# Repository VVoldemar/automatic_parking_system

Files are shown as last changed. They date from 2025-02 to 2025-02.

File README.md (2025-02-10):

# Automatic Parking System

<div>
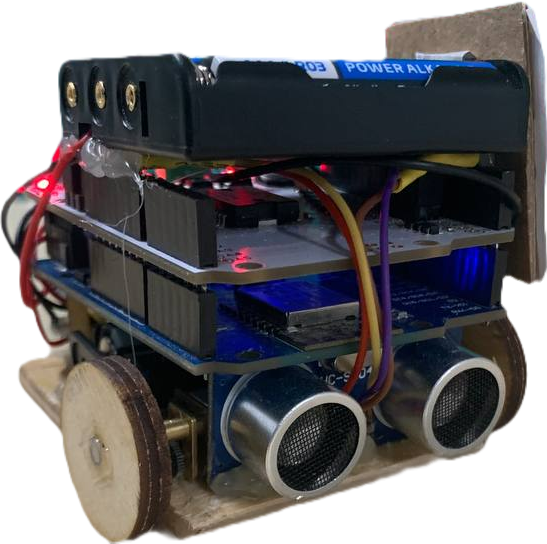
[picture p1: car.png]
    
    Данный репозиторий содержит материалы проекта "Модель автоматической парковки", разработанного для участия в Московской предпрофессиональной олимпиаде школьников, профиль "Инженерия".
</div>

## Описание проекта

Проект представляет собой программно-аппаратный комплекс (ПАК), реализующий автоматическую парковку модели автомобиля.  Система включает в себя следующие подсистемы:

*   **ПРА (Подсистема распознавания автомобиля):**  Отвечает за идентификацию автомобиля по QR-коду.
*   **ППЯ (Подсистема перемещения ячеек):**  Обеспечивает перемещение ячеек парковки.
*   **ПАУ (Подсистема автоматического управления):**  Координирует работу всех подсистем, управляет процессом парковки и хранения данных.
*   **ПБА (Подсистема беспилотного автомобиля):**  Модель автомобиля, способная к автономному перемещению.

## Внешний вид пользовательского интерфейса
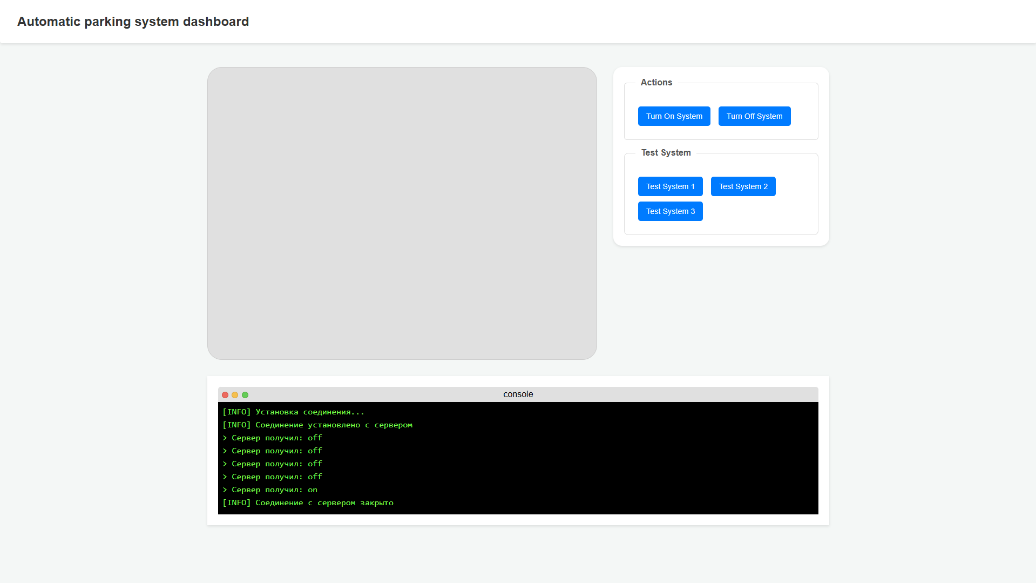
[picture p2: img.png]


_Предоставлен исключительно для справки, может отличаться_

## Структура репозитория

*   **Программный код:** Исходный код программного обеспечения ПАК.
*   **3D-модели:** Файлы 3D-моделей элементов системы.
*   **Видеоролик:** Ссылка на видеоролик, демонстрирующие работу системы.
*   **Фото:** Фотографии устройства

## Сборка и запуск
1.  Установите необходимые библиотеки: `pip install -r requirements.txt`
2.  Подключите Arduino к компьютеру.
3.  Загрузите скетч `esp.ino` на модуль на основе ESP8266.
4.  Запустите программу: `python main.py`

- Для просмотра модели общей сборки проекта, используйте программу **SolidWorks**

## Команда

*   Еремкин Степан
*   Вершок Владимир
*   Шишкин Степан
*   Брюханов Михаил
*   Пикулин Виктор
*   Руководитель: Шапошников Филипп Владимирович

_Подробное описание проекта, технические характеристики, результаты испытаний и прочая информация содержатся в отчетной документации._

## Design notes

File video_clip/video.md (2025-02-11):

Ссылка на видеоролик: https://vkvideo.ru/video506153733_456239018?list=ln-Q410VyUmrbDWpCRAAN

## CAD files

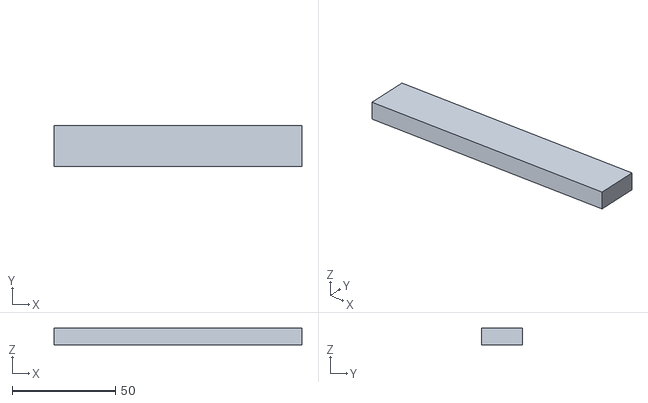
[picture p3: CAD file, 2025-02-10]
3d_models/предпроф ножка всего.STL
120.0 x 20.0 x 8.00

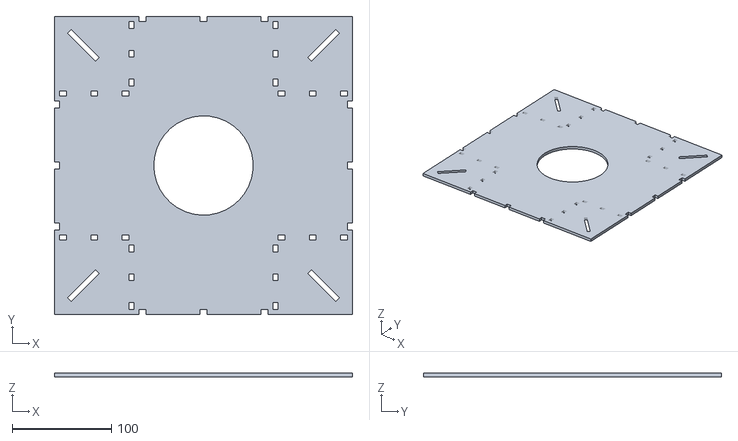
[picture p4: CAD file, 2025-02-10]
3d_models/предпроф 2 этаж.STL
300.0 x 300.0 x 4.00

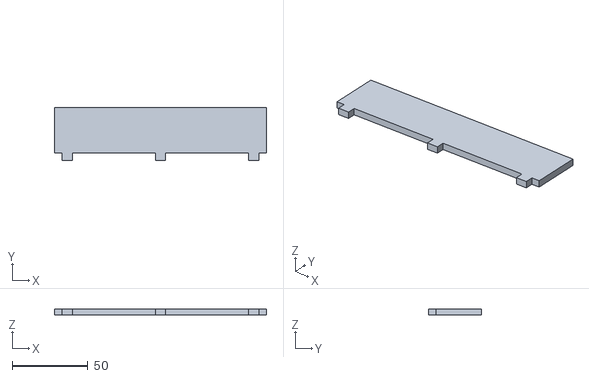
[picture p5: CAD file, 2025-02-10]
3d_models/предпроф бортик большой.STL
140.0 x 35.0 x 4.00

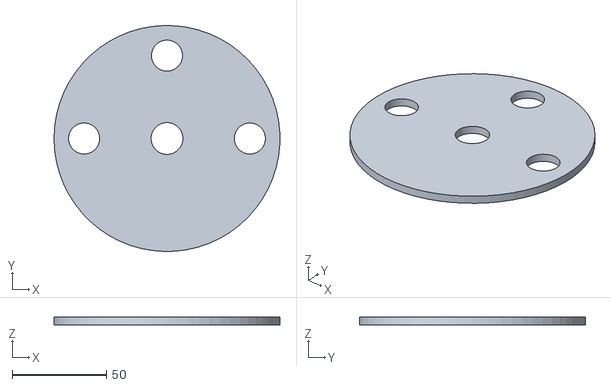
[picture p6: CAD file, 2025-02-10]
3d_models/предпроф колесо лифта верхнее 120мм.STL
120.0 x 120.0 x 4.00

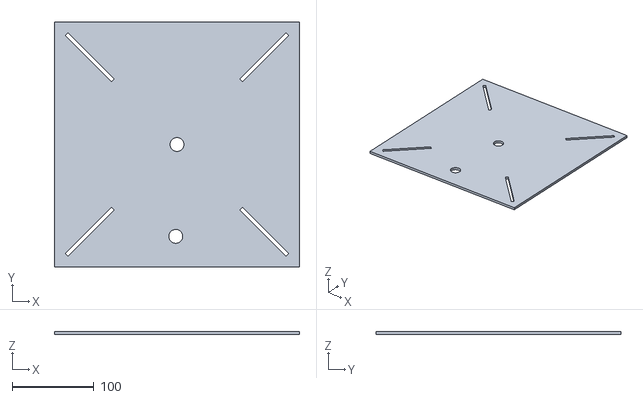
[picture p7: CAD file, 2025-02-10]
3d_models/предпроф основание подвала.STL
300.0 x 300.0 x 4.00

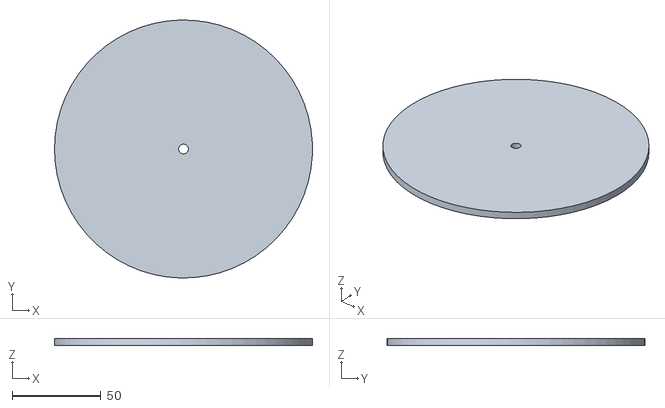
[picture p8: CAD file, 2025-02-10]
3d_models/предпроф колесо лифта нижнее 145мм.STL
145.0 x 145.0 x 4.00

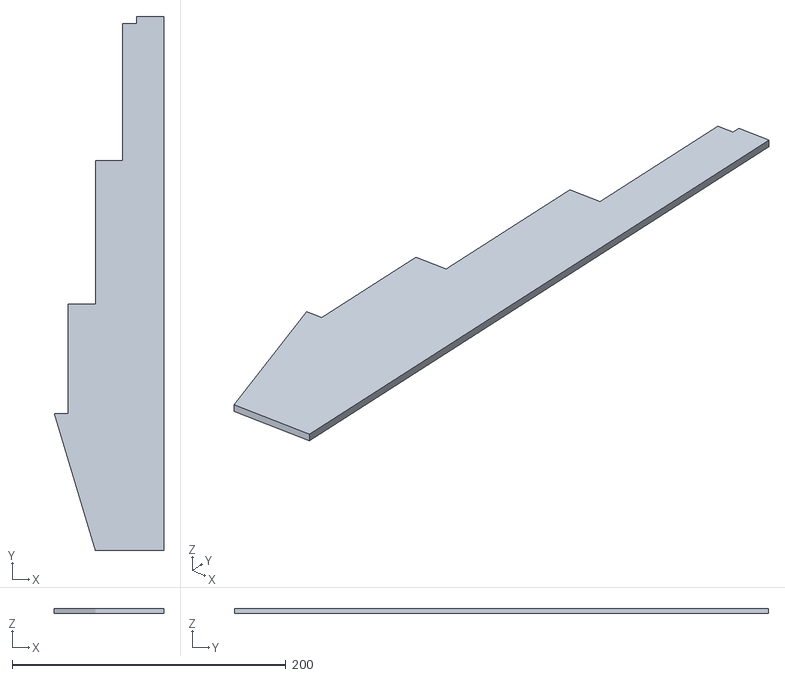
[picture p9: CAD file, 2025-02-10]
3d_models/предпроф опора чтоб ты в аду горела.STL
80.0 x 390.0 x 4.00

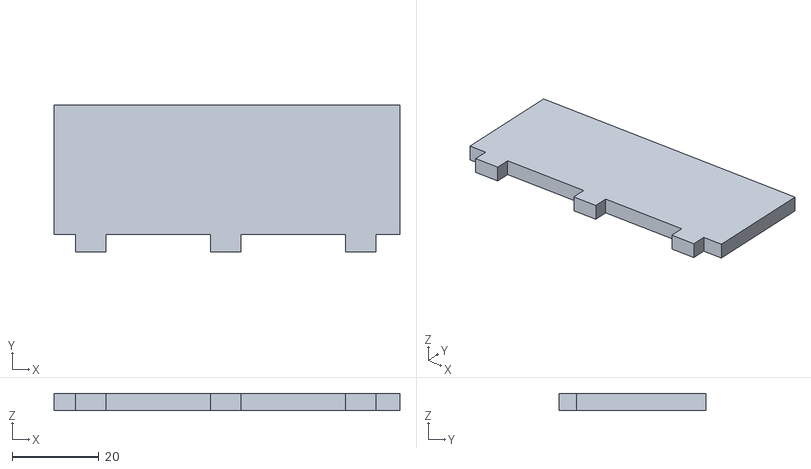
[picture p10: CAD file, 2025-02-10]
3d_models/предпроф бортик малый 1.STL
80.0 x 34.1 x 4.00

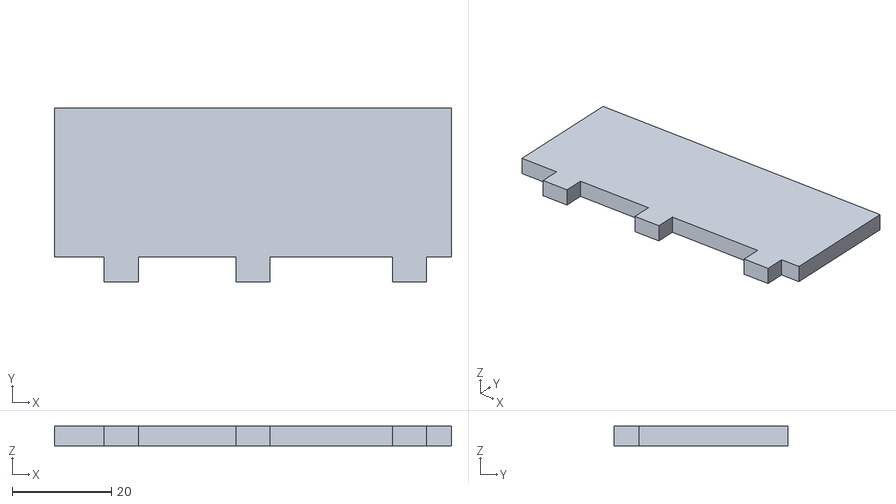
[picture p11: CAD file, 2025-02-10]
3d_models/предпроф бортик малый 10мм.STL
80.0 x 35.0 x 4.00

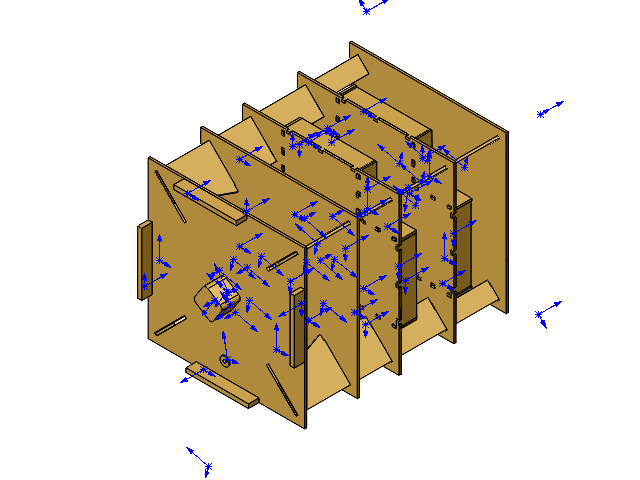
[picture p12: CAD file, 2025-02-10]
3d_models/предпроф сборка надеюсь конечная.SLDASM
предпроф основание подвала
предпроф ножка всего x 4
предпроф опора чтоб ты в аду горела x 4
предпроф заезд
предпроф 1 этаж
предпроф бортик большой x 8
предпроф бортик малый по 5мм x 7
предпроф бортик малый 10мм x 9
предпроф 2 этаж
предпроф потолок
предпроф подшибник x 7
предпроф колесо лифта нижнее 145мм
предпроф размер шагового двигателя x 4
предпроф шпилька двигателя x 4
предпроф шпилька лифта x 3
предпроф платформа лифта 95мм
предпроф колесо лифта верхнее 120мм
предпроф шпилька 6мм 40мм

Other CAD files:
3d_models/предпроф заезд.STL
3d_models/предпроф 1 этаж.STL

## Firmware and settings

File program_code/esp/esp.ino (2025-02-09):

#include <ESP8266WiFi.h>
// #include <MQTTClient.h>
#include <MQTT.h>

#define LEFT_WHEEL D5
#define RIGHT_WHEEL D6
#define LEFT_WHEEL_DIRECTION D4 
#define RIGHT_WHEEL_DIRECTION D7

#define TRIG_PIN D2
#define ECHO_PIN D3

#define SOUND_SPEED 0.034

// #define NO_DISTANCE_MODULE

const char WIFI_SSID[] = "MQTTT-1";
const char WIFI_PASSWORD[] = "11223344";

const char MQTT_BROKER_ADRRESS[] = "10.42.0.1";
const int MQTT_PORT = 1883;
const char MQTT_CLIENT_ID[] = "esp";
const char MQTT_USERNAME[] = "";
const char MQTT_PASSWORD[] = "";

const char PUBLISH_TOPIC[] = "esp";
const char SUBSCRIBE_TOPIC[] = "rasp";

const int PUBLISH_INTERVAL = 10000;

WiFiClient network;
MQTTClient mqtt = MQTTClient(256);

unsigned long lastPublishTime = 0;

int forward_stop_distance = 5;
int backward_stop_distance = 5;
int left_motor_speed = 255;
int right_motor_speed = 255;
int delay_after_distance = 200;

void setup() {
  Serial.begin(9600);

  pinMode(D4, OUTPUT);
  pinMode(D5, OUTPUT);
  pinMode(D6, OUTPUT);
  pinMode(D7, OUTPUT);
  pinMode(TRIG_PIN, OUTPUT);
  pinMode(ECHO_PIN, INPUT);

  int status = WL_IDLE_STATUS;
  while (status != WL_CONNECTED) {
    Serial.print("Arduino - Attempting to connect to SSID: ");
    Serial.println(WIFI_SSID);
    status = WiFi.begin(WIFI_SSID, WIFI_PASSWORD);
    Serial.println(status);
    delay(5000);
  }

  Serial.print("IP Address: ");
  Serial.println(WiFi.localIP());

  connectToRB();

  sendToRB("hello");
}

void loop() {
  mqtt.loop();

  if (millis() - lastPublishTime > PUBLISH_INTERVAL) {
    sendToRB(String(millis()));
    lastPublishTime = millis();
  }
}

void connectToRB() {
  mqtt.begin(MQTT_BROKER_ADRRESS, MQTT_PORT, network);

  mqtt.onMessage(messageHandler);

  Serial.print("Arduino - Connecting to MQTT broker");

  while (!mqtt.connect(MQTT_CLIENT_ID, MQTT_USERNAME, MQTT_PASSWORD)) {
    Serial.print(".");
    delay(100);
  }
  Serial.println();

  if (!mqtt.connected()) {
    Serial.println("Arduino - MQTT broker Timeout!");
    return;
  }

  if (mqtt.subscribe(SUBSCRIBE_TOPIC)){
    Serial.print("Arduino - Subscribed to the topic: ");
  } else {
    Serial.print("Arduino - Failed to subscribe to the topic: ");
  }

  Serial.println(SUBSCRIBE_TOPIC);
  Serial.println("Arduino - MQTT broker Connected!");
}

void sendToRB(const String &data) {
  mqtt.publish(PUBLISH_TOPIC, data);

  Serial.print("Arduino - sent to MQTT:");
  Serial.println(data);
}

void setConfig(String &payload) {
  // parse the payload and set the config
  switch (payload[6])
  { 
  case 'F':
    forward_stop_distance = payload.substring(8).toFloat();
    break;
  case 'B':
    backward_stop_distance = payload.substring(8).toFloat();
    break;
  case 'L':
    left_motor_speed = payload.substring(8).toFloat();
    break;
  case 'R':
    right_motor_speed = payload.substring(8).toFloat();
    break;
  case 'D':
    delay_after_distance = payload.substring(8).toInt();
    break;
  }
  Serial.println("Arduino - set config: " + 
    String(forward_stop_distance) + " " + 
    String(backward_stop_distance) + " " +
    String(left_motor_speed) + " " +
    String(right_motor_speed) + " " +
    String(delay_after_distance));

  sendToRB("ok config");
}

void messageHandler(String &topic, String &payload) {
  if (payload.length() >= 6 && payload.substring(0, 6) == "config"){
    setConfig(payload);
  }

  else if (payload == "forward"){
    moveForward();
  }

  else if (payload == "backward"){
    moveBackward();
  }
}

void moveForward(){
  sendToRB("ok forward");  // why just don't use json?

  analogWrite(LEFT_WHEEL, left_motor_speed);
  analogWrite(RIGHT_WHEEL, right_motor_speed);
  digitalWrite(LEFT_WHEEL_DIRECTION, LOW);
  digitalWrite(RIGHT_WHEEL_DIRECTION, HIGH);

  while (!enoughDistance(forward_stop_distance)){
    delay(100);
  }

  delay(delay_after_distance);

  digitalWrite(LEFT_WHEEL, LOW);
  digitalWrite(RIGHT_WHEEL, LOW);
  digitalWrite(LEFT_WHEEL_DIRECTION, LOW);
  digitalWrite(RIGHT_WHEEL_DIRECTION, LOW);

  sendToRB("done forward");  // why just don't use json?
}

bool enoughDistance(int &dist){
#ifdef NO_DISTANCE_MODULE
  delay(2000);
  return true;
#else
  return getDistance() <= dist;
#endif
}

float getDistance(){
  digitalWrite(TRIG_PIN, LOW);
  delayMicroseconds(2);

  digitalWrite(TRIG_PIN, HIGH);
  delayMicroseconds(10);
  digitalWrite(TRIG_PIN, LOW);
  
  long duration = pulseIn(ECHO_PIN, HIGH);
  float distanceCm = duration * SOUND_SPEED / 2.0;

  Serial.print("Distance (cm): ");
  Serial.println(distanceCm);
  return distanceCm;
}

void moveBackward(){
  sendToRB("ok backward");  // why just don't use json?

  analogWrite(LEFT_WHEEL, left_motor_speed);
  analogWrite(RIGHT_WHEEL, right_motor_speed);
  digitalWrite(LEFT_WHEEL_DIRECTION, HIGH);
  digitalWrite(RIGHT_WHEEL_DIRECTION, LOW);

  delay(delay_after_distance);

  while (enoughDistance(backward_stop_distance)){
    delay(100);
  }

  digitalWrite(LEFT_WHEEL, LOW);
  digitalWrite(RIGHT_WHEEL, LOW);
  digitalWrite(LEFT_WHEEL_DIRECTION, LOW);
  digitalWrite(RIGHT_WHEEL_DIRECTION, LOW);

  sendToRB("done backward");  // why just don't use json?
}

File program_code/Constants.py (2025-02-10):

STEPS_IN_360DEG = -1620
STEPS_IN_QUATER_ROTATION = STEPS_IN_360DEG // 4

STEPS_IN_FLOOR1 = -12500
STEPS_IN_FLOOR2 = -16900
STEPS_IN_BOTH_FLOORS = STEPS_IN_FLOOR1 + STEPS_IN_FLOOR2

DELAY_VERTICAL = 500 * 1e-6
DELAY_HORIZONTAL = 2000 * 1e-6  

MOTOR_VERTICAL1_PULSE = 5
MOTOR_VERTICAL1_DIRECTION = 6
MOTOR_VERTICAL2_PULSE = 23
MOTOR_VERTICAL2_DIRECTION = 24
MOTOR_VERTICAL3_PULSE = 20
MOTOR_VERTICAL3_DIRECTION = 21

MOTOR_HORIZONTAL_PULSE = 17
MOTOR_HORIZONTAL_DIRECTION = 27

FORWARD_STOP_DISTANCE = 4
BACKWARD_STOP_DISTANCE = 10

LEFT_MOTOR_SPEED = 60
RIGHT_MOTOR_SPEED = 55

AFTER_STOP_DISTANCE_DELAY = 600

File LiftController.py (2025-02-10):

from MotorController import MotorController
import Constants
from typing import Union
import logging

class LiftController:
    vertical_motors: list[MotorController]
    horizontal_motor: MotorController

    rotation: int # clockwise increases
    floor: int

    def __init__(self,
                 horizontal_motor: Union[MotorController, None] = None,
                 vertical_motors: Union[list[MotorController], None] = None):
        if not horizontal_motor:
            horizontal_motor = MotorController(
                Constants.MOTOR_HORIZONTAL_DIRECTION,
                Constants.MOTOR_HORIZONTAL_PULSE,
                Constants.DELAY_HORIZONTAL
            )
        if not vertical_motors:
            vertical_motors = [
                MotorController(
                    Constants.MOTOR_VERTICAL1_DIRECTION,
                    Constants.MOTOR_VERTICAL1_PULSE,
                    Constants.DELAY_VERTICAL
                ),
                MotorController(
                    Constants.MOTOR_VERTICAL2_DIRECTION,
                    Constants.MOTOR_VERTICAL2_PULSE,
                    Constants.DELAY_VERTICAL
                ),
                MotorController(
                    Constants.MOTOR_VERTICAL3_DIRECTION,
                    Constants.MOTOR_VERTICAL3_PULSE,
                    Constants.DELAY_VERTICAL
                ),
            ]
            
        self.vertical_motors = vertical_motors
        self.horizontal_motor = horizontal_motor

        self.floor = 0
        self.rotation = 0

        logging.info("LiftController initialized")

    def move_to(self, floor: int, rotation: int):
        if not 0 <= floor < 3:
            logging.error(f"Invalid floor: {floor}")
            return

        rel_floor = floor - self.floor

        rel_rot = rotation - self.rotation
        rel_rot %= 4
        if rel_rot > 2:
            rel_rot -= 4
        
        vert_steps = 0
        if rel_floor == 2:
            vert_steps = Constants.STEPS_IN_BOTH_FLOORS
        elif rel_floor == -2:
            vert_steps = -Constants.STEPS_IN_BOTH_FLOORS
        elif rel_floor == 1:
            if self.floor == 0:
                vert_steps = Constants.STEPS_IN_FLOOR1
            elif self.floor == 1:
                vert_steps = Constants.STEPS_IN_FLOOR2
        elif rel_floor == -1:
            if self.floor == 2:
                vert_steps = -Constants.STEPS_IN_FLOOR2
            elif self.floor == 1:
                vert_steps = -Constants.STEPS_IN_FLOOR1
        # print(self.floor, rel_floor, vert_steps)
        
        tasks = [motor.run_go_steps(vert_steps // 2) for motor in self.vertical_motors]
        for i in tasks:
            i.join()

        self.horizontal_motor.go_steps(rel_rot * Constants.STEPS_IN_QUATER_ROTATION)

        tasks = [motor.run_go_steps(vert_steps // 2) for motor in self.vertical_motors]
        for i in tasks:
            i.join()
        
        self.floor = floor
        self.rotation = rotation

        logging.info(f"Moved to floor: {floor}, rotation: {rotation}")

    def clean_up(self):
        self.horizontal_motor.clean_up()
        for motor in self.vertical_motors:
            motor.clean_up()
        logging.info("LiftController cleaned up")

if __name__ == "__main__":
    lift = LiftController()
    while True:
        s = input().split()
        lift.move_to(int(s[0]), int(s[1]))

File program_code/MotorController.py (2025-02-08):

import RPi.GPIO as GPIO
from time import sleep

from threading import Thread
import logging

class MotorController:
    _direction_pin: int
    _pulse_pin: int

    delay: float
    possition: int

    def __init__(self, direction_pin: int, pulse_pin: int, delay: float):
        GPIO.setmode(GPIO.BCM)

        GPIO.setup(direction_pin, GPIO.OUT)
        GPIO.setup(pulse_pin, GPIO.OUT)

        self._direction_pin = direction_pin
        self._pulse_pin = pulse_pin
        self.delay = delay

        self.possition = 0
        logging.info(f"MotorController initialized with direction_pin={direction_pin}, pulse_pin={pulse_pin}")

    def run_go_steps(self, steps_num: int) -> Thread:
        thread = Thread(target=self.go_steps, args=[steps_num])
        
        thread.start()
        return thread

    def go_steps(self, steps_num: int) -> None:
        is_clockwise = steps_num >= 0
        steps_num = abs(steps_num)

        logging.info(f"Rotating {steps_num} steps on {self._pulse_pin} pin")
        for _ in range(steps_num):
            self.pulse(is_clockwise)
        logging.info(f"Rotation completed on {self._pulse_pin} pin")

    def pulse(self, is_clockwise: bool):
        GPIO.output(self._direction_pin, not is_clockwise)
        
        GPIO.output(self._pulse_pin, GPIO.HIGH)
        sleep(self.delay)
        GPIO.output(self._pulse_pin, GPIO.LOW)
        sleep(self.delay)

        self.possition += 1 if is_clockwise else -1

    def clean_up(self):
        GPIO.cleanup(self._direction_pin)
        GPIO.cleanup(self._pulse_pin)
        logging.info("MotorController cleaned up")

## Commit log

2025-01-27 add SocketServer
2025-01-30 Lift, motor controllers, constants
2025-02-08 index.html + server address fix, websockets do not work :(
    [Camera.py, Core.py, MQTTServer.py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]
2025-02-09 ugly motor controlling buttons in web, normar working shutdown, working websockets in remote (with innormus delay, bruh)
2025-02-09 camera stream
2025-02-10 Repository has been redesigned to meet the Olympiad's requirements
    [предпроф 1 этаж.STL, предпроф 2 этаж.STL, предпроф бортик большой.STL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]
